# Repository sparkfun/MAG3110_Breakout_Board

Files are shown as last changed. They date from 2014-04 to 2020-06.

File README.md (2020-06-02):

**NOTE:** *This product has been retired from our catalog. If you are looking for more up-to-date info, please check out some of these resources to see how other users are still hacking and improving on this product.*
* *[SparkFun Forum](https://forum.sparkfun.com/)*
* *[Comments Here on GitHub](https://github.com/sparkfun/MAG3110_Breakout_Board/issues)*

Triple Axis Magnetometer Breakout - MAG3110
============================================

_MAG-3110 (https://www.sparkfun.com/products/12670)_

[*Triple Axis Magnetometer Breakout - MAG3110 (SEN-12670)*](https://www.sparkfun.com/products/12670)

Breakout board for MAG3110 digital magnetometer [The datasheet can be found here.](https://dlnmh9ip6v2uc.cloudfront.net/datasheets/Sensors/Magneto/MAG3110.pdf)

This board was created in Eagle v6.5.0. 

Repository Contents
-------------------

* **/Hardware** - All Eagle design files (.brd and .sch)
* **/Libraries** - Arduino libraries
* **/Production** - Production panel files

Documentation
--------------

* **[Library](https://github.com/sparkfun/SparkFun_MAG3110_Breakout_Board_Arduino_Library)** - Arduino library 
* **[Hookup Guide](https://learn.sparkfun.com/tutorials/mag3110-magnetometer-hookup-guide-)** - Basic hookup guide 
* **[SparkFun Fritzing repo](https://github.com/sparkfun/Fritzing_Parts)** - Fritzing diagrams for SparkFun products.
* **[SparkFun 3D Model repo](https://github.com/sparkfun/3D_Models)** - 3D models of SparkFun products. 
* **[SparkFun Graphical Datasheets](https://github.com/sparkfun/Graphical_Datasheets)** -Graphical Datasheets for various SparkFun products.

Version History
---------------

* [V_H1.2](https://github.com/sparkfun/MAG3110_Breakout_Board/releases/tag/vH1.2) - Removing old libraries. Adding links to formal libs in readme.
* [V_H1.2_L1.1.0](https://github.com/sparkfun/MAG3110_Breakout_Board/releases/tag/vH1.2_L1.0)

Product Versions
---------------

* [SEN-10619](https://www.sparkfun.com/products/12670) - Version 1.2
* [SEN-10619](https://www.sparkfun.com/products/retired/10619) - Version 1.1 of the Sensor
 
License Information
-------------------
This product is _**open source**_! 

Please review the LICENSE.md file for license information. 

If you have any questions or concerns on licensing, please contact technical support on our [SparkFun forums](https://forum.sparkfun.com/viewforum.php?f=152).

Distributed as-is; no warranty is given.

- Your friends at SparkFun.

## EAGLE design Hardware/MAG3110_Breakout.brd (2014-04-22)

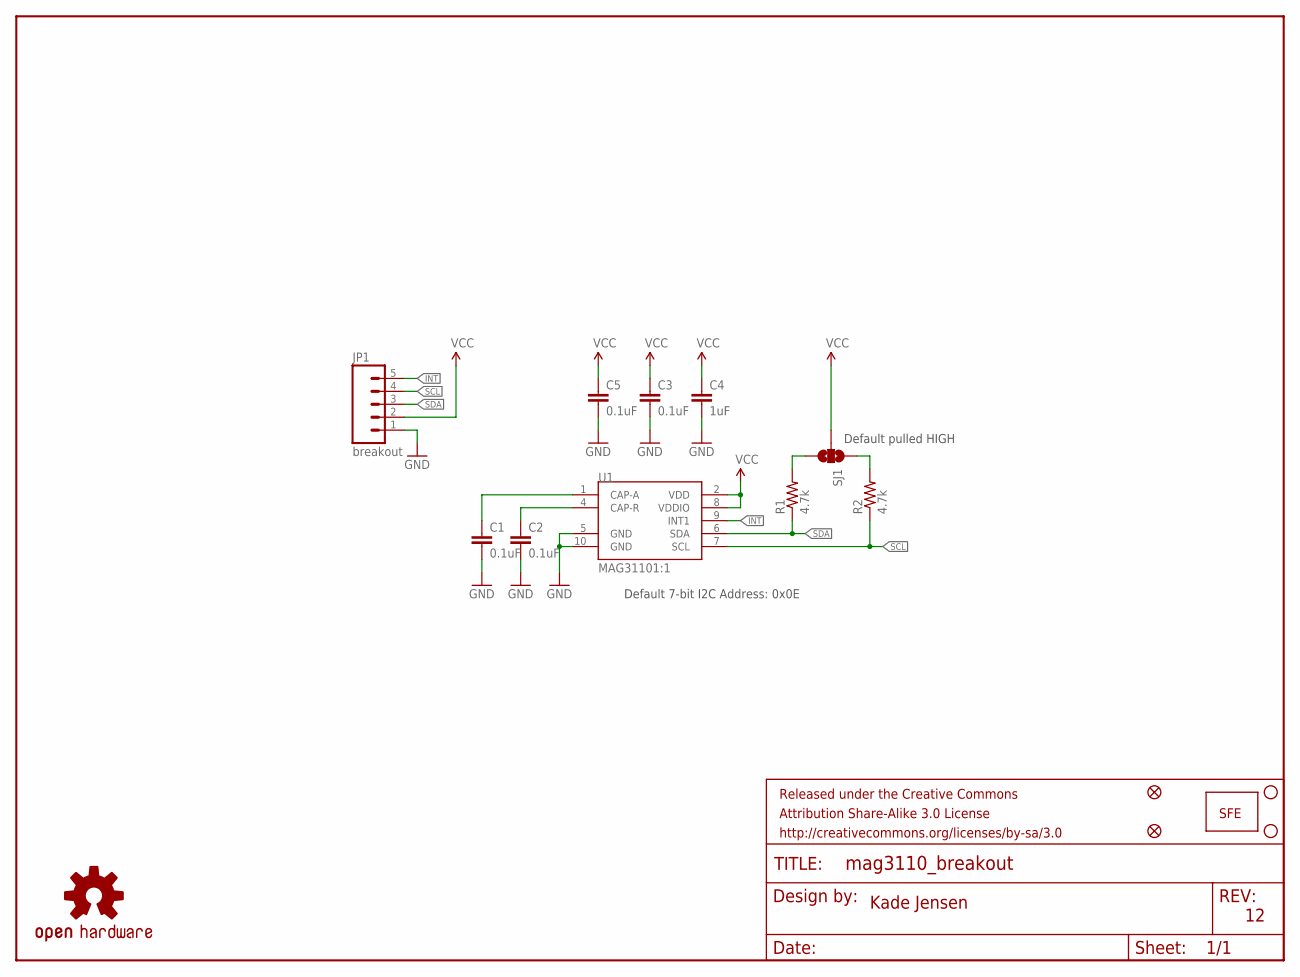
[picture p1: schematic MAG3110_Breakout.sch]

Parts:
C1, C2, C3, C5: 0.1uF; 0603-CAP
C4: 1uF; 0603-CAP
FID1, FID2: FIDUCIAL1X2; FIDUCIAL-1X2
FRAME2: FRAME-LETTER; CREATIVE_COMMONS
JP1: breakout; 1X05
JP2, JP3: STAND-OFF
JP7: LOGO-SFESK; SFE-LOGO-FLAME
LOGO1: OSHW-LOGOS; OSHW-LOGO-S
R1, R2: 4.7k; 0603-RES
SJ1: SOLDERJUMPER_2WAYPASTE1&2&3; SJ_3_PASTE1&2&3
U1: MAG31101:1; DFN-10-W

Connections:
GND: C1.2, C2.2, C3.2, C4.2, C5.2, JP1.1, U1.5 (GND), U1.10 (GND)
INT: JP1.5, U1.9 (INT1)
unnamed: C2.1, U1.4 (CAP-R)
unnamed: C1.1, U1.1 (CAP-A)
unnamed: R2.2, SJ1.1
unnamed: R1.2, SJ1.3
SCL: JP1.4, R2.1, U1.7 (SCL)
SDA: JP1.3, R1.1, U1.6 (SDA)
VCC: C3.1, C4.1, C5.1, JP1.2, SJ1.2, U1.2 (VDD), U1.8 (VDDIO)

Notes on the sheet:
Kade Jensen
Default pulled HIGH
Default 7-bit I2C Address: 0x0E

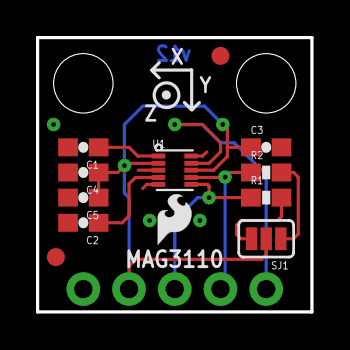
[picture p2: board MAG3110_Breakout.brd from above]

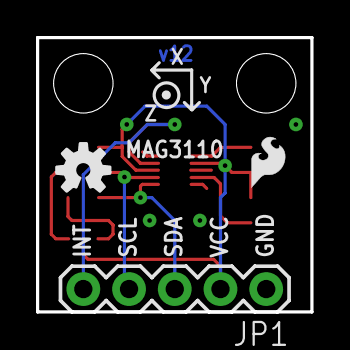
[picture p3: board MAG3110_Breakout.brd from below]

Board: 2 copper layers, 15.2 x 15.2 mm, 18 parts (3 on the bottom side), 9 nets.

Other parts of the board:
JP4: LOGO-SFESK; SFE-LOGO-FLAME

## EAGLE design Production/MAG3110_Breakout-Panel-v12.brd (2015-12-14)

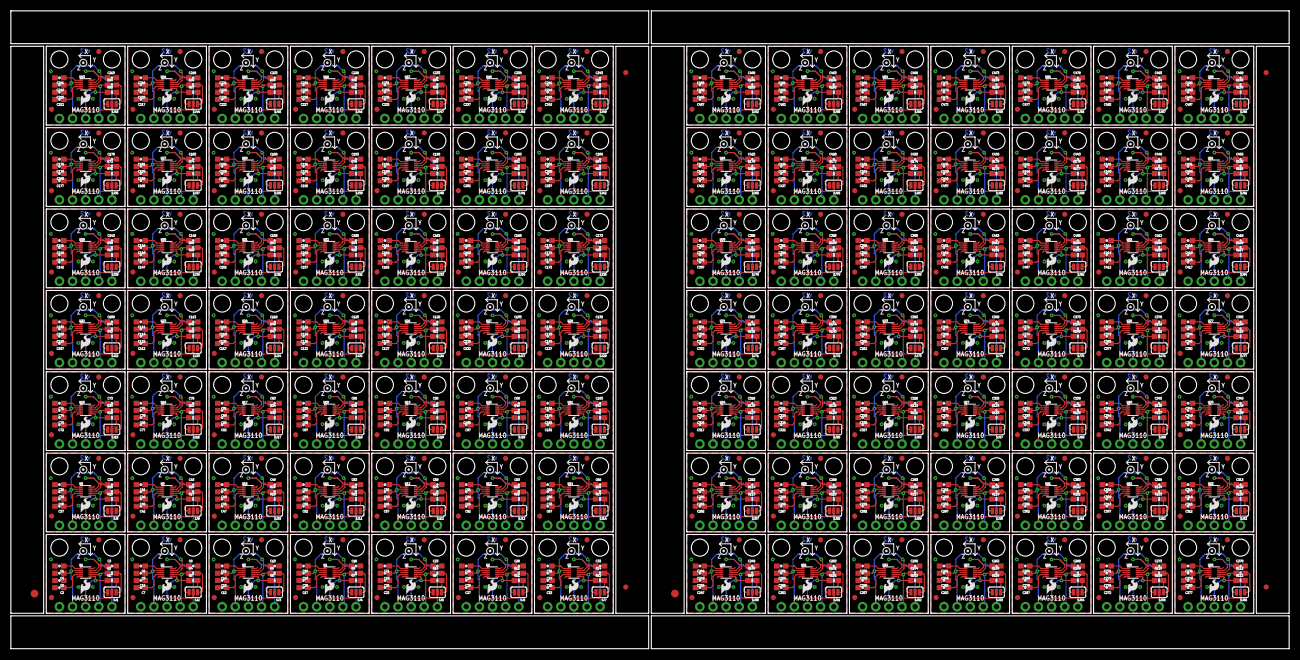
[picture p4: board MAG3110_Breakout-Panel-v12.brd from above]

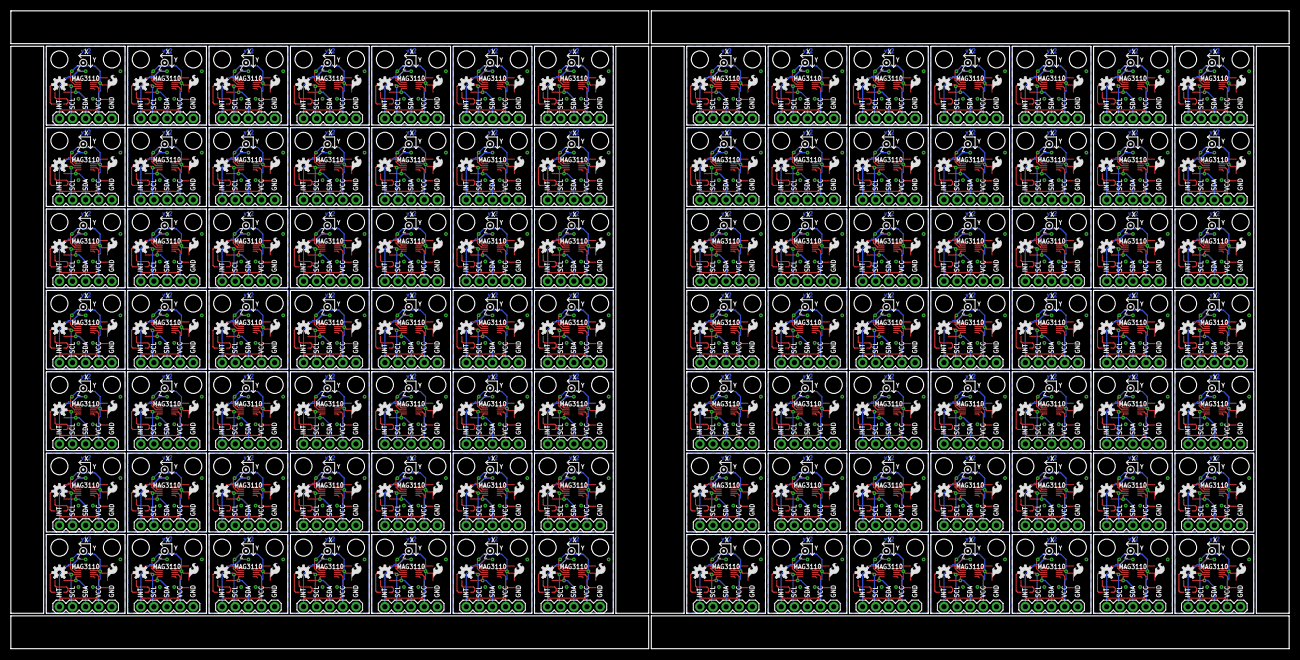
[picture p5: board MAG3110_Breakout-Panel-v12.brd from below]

Board: 2 copper layers, 247.4 x 123.4 mm, 1672 parts (294 on the bottom side), 882 nets.

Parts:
C1, C2, C3, C5, C6, C7, C8, C10, C11, C12, C13, C15, C16, C17, C18, C20, C21, C22, C23, C25, C26, C27, C28, C30, C31, C32, C33, C35, C36, C37, C38, C40, C41, C42, C43, C45, C46, C47, C48, C50, C51, C52, C53, C55, C56, C57, C58, C60, C61, C62, C63, C65, C66, C67, C68, C70, C71, C72, C73, C75, C76, C77, C78, C80, C81, C82, C83, C85, C86, C87, C88, C90, C91, C92, C93, C95, C96, C97, C98, C100, C101, C102, C103, C105, C106, C107, C108, C110, C111, C112, C113, C115, C116, C117, C118, C120, C121, C122, C123, C125, C126, C127, C128, C130, C131, C132, C133, C135, C136, C137, C138, C140, C141, C142, C143, C145, C146, C147, C148, C150, C151, C152, C153, C155, C156, C157, C158, C160, C161, C162, C163, C165, C166, C167, C168, C170, C171, C172, C173, C175, C176, C177, C178, C180, C181, C182, C183, C185, C186, C187, C188, C190, C191, C192, C193, C195, C196, C197, C198, C200, C201, C202, C203, C205, C206, C207, C208, C210, C211, C212, C213, C215, C216, C217, C218, C220, C221, C222, C223, C225, C226, C227, C228, C230, C231, C232, C233, C235, C236, C237, C238, C240, C241, C242, C243, C245, C246, C247, C248, C250, C251, C252, C253, C255, C256, C257, C258, C260, C261, C262, C263, C265, C266, C267, C268, C270, C271, C272, C273, C275, C276, C277, C278, C280, C281, C282, C283, C285, C286, C287, C288, C290, C291, C292, C293, C295, C296, C297, C298, C300, C301, C302, C303, C305, C306, C307, C308, C310, C311, C312, C313, C315, C316, C317, C318, C320, C321, C322, C323, C325, C326, C327, C328, C330, C331, C332, C333, C335, C336, C337, C338, C340, C341, C342, C343, C345, C346, C347, C348, C350, C351, C352, C353, C355, C356, C357, C358, C360, C361, C362, C363, C365, C366, C367, C368, C370, C371, C372, C373, C375, C376, C377, C378, C380, C381, C382, C383, C385, C386, C387, C388, C390, C391, C392, C393, C395, C396, C397, C398, C400, C401, C402, C403, C405, C406, C407, C408, C410, C411, C412, C413, C415, C416, C417, C418, C420, C421, C422, C423, C425, C426, C427, C428, C430, C431, C432, C433, C435, C436, C437, C438, C440, C441, C442, C443, C445, C446, C447, C448, C450, C451, C452, C453, C455, C456, C457, C458, C460, C461, C462, C463, C465, C466, C467, C468, C470, C471, C472, C473, C475, C476, C477, C478, C480, C481, C482, C483, C485, C486, C487, C488, C490: 0.1uF; 0603-CAP
C4, C9, C14, C19, C24, C29, C34, C39, C44, C49, C54, C59, C64, C69, C74, C79, C84, C89, C94, C99, C104, C109, C114, C119, C124, C129, C134, C139, C144, C149, C154, C159, C164, C169, C174, C179, C184, C189, C194, C199, C204, C209, C214, C219, C224, C229, C234, C239, C244, C249, C254, C259, C264, C269, C274, C279, C284, C289, C294, C299, C304, C309, C314, C319, C324, C329, C334, C339, C344, C349, C354, C359, C364, C369, C374, C379, C384, C389, C394, C399, C404, C409, C414, C419, C424, C429, C434, C439, C444, C449, C454, C459, C464, C469, C474, C479, C484, C489: 1uF; 0603-CAP
E$1, E$5: FIDUCIAL-1.5X3
E$2, E$3, E$4, E$6: FIDUCIAL-1X2
FID1, FID2, FID3, FID4, FID5, FID6, FID7, FID8, FID9, FID10, FID11, FID12, FID13, FID14, FID15, FID16, FID17, FID18, FID19, FID20, FID21, FID22, FID23, FID24, FID25, FID26, FID27, FID28, FID29, FID30, FID31, FID32, FID33, FID34, FID35, FID36, FID37, FID38, FID39, FID40, FID41, FID42, FID43, FID44, FID45, FID46, FID47, FID48, FID49, FID50, FID51, FID52, FID53, FID54, FID55, FID56, FID57, FID58, FID59, FID60, FID61, FID62, FID63, FID64, FID65, FID66, FID67, FID68, FID69, FID70, FID71, FID72, FID73, FID74, FID75, FID76, FID77, FID78, FID79, FID80, FID81, FID82, FID83, FID84, FID85, FID86, FID87, FID88, FID89, FID90, FID91, FID92, FID93, FID94, FID95, FID96, FID97, FID98, FID99, FID100, FID101, FID102, FID103, FID104, FID105, FID106, FID107, FID108, FID109, FID110, FID111, FID112, FID113, FID114, FID115, FID116, FID117, FID118, FID119, FID120, FID121, FID122, FID123, FID124, FID125, FID126, FID127, FID128, FID129, FID130, FID131, FID132, FID133, FID134, FID135, FID136, FID137, FID138, FID139, FID140, FID141, FID142, FID143, FID144, FID145, FID146, FID147, FID148, FID149, FID150, FID151, FID152, FID153, FID154, FID155, FID156, FID157, FID158, FID159, FID160, FID161, FID162, FID163, FID164, FID165, FID166, FID167, FID168, FID169, FID170, FID171, FID172, FID173, FID174, FID175, FID176, FID177, FID178, FID179, FID180, FID181, FID182, FID183, FID184, FID185, FID186, FID187, FID188, FID189, FID190, FID191, FID192, FID193, FID194, FID195, FID196: FIDUCIAL1X2; FIDUCIAL-1X2
JP1, JP5, JP11, JP16, JP21, JP26, JP31, JP36, JP41, JP46, JP51, JP56, JP61, JP66, JP71, JP76, JP81, JP86, JP91, JP96, JP101, JP106, JP111, JP116, JP121, JP126, JP131, JP136, JP141, JP146, JP151, JP156, JP161, JP166, JP171, JP176, JP181, JP186, JP191, JP196, JP201, JP206, JP211, JP216, JP221, JP226, JP231, JP236, JP241, JP246, JP251, JP256, JP261, JP266, JP271, JP276, JP281, JP286, JP291, JP296, JP301, JP306, JP311, JP316, JP321, JP326, JP331, JP336, JP341, JP346, JP351, JP356, JP361, JP366, JP371, JP376, JP381, JP386, JP391, JP396, JP401, JP406, JP411, JP416, JP421, JP426, JP431, JP436, JP441, JP446, JP451, JP456, JP461, JP466, JP471, JP476, JP481, JP486: breakout; 1X05
JP2, JP3, JP6, JP8, JP12, JP13, JP17, JP18, JP22, JP23, JP27, JP28, JP32, JP33, JP37, JP38, JP42, JP43, JP47, JP48, JP52, JP53, JP57, JP58, JP62, JP63, JP67, JP68, JP72, JP73, JP77, JP78, JP82, JP83, JP87, JP88, JP92, JP93, JP97, JP98, JP102, JP103, JP107, JP108, JP112, JP113, JP117, JP118, JP122, JP123, JP127, JP128, JP132, JP133, JP137, JP138, JP142, JP143, JP147, JP148, JP152, JP153, JP157, JP158, JP162, JP163, JP167, JP168, JP172, JP173, JP177, JP178, JP182, JP183, JP187, JP188, JP192, JP193, JP197, JP198, JP202, JP203, JP207, JP208, JP212, JP213, JP217, JP218, JP222, JP223, JP227, JP228, JP232, JP233, JP237, JP238, JP242, JP243, JP247, JP248, JP252, JP253, JP257, JP258, JP262, JP263, JP267, JP268, JP272, JP273, JP277, JP278, JP282, JP283, JP287, JP288, JP292, JP293, JP297, JP298, JP302, JP303, JP307, JP308, JP312, JP313, JP317, JP318, JP322, JP323, JP327, JP328, JP332, JP333, JP337, JP338, JP342, JP343, JP347, JP348, JP352, JP353, JP357, JP358, JP362, JP363, JP367, JP368, JP372, JP373, JP377, JP378, JP382, JP383, JP387, JP388, JP392, JP393, JP397, JP398, JP402, JP403, JP407, JP408, JP412, JP413, JP417, JP418, JP422, JP423, JP427, JP428, JP432, JP433, JP437, JP438, JP442, JP443, JP447, JP448, JP452, JP453, JP457, JP458, JP462, JP463, JP467, JP468, JP472, JP473, JP477, JP478, JP482, JP483, JP487, JP488: STAND-OFF
JP4, JP7, JP9, JP10, JP14, JP15, JP19, JP20, JP24, JP25, JP29, JP30, JP34, JP35, JP39, JP40, JP44, JP45, JP49, JP50, JP54, JP55, JP59, JP60, JP64, JP65, JP69, JP70, JP74, JP75, JP79, JP80, JP84, JP85, JP89, JP90, JP94, JP95, JP99, JP100, JP104, JP105, JP109, JP110, JP114, JP115, JP119, JP120, JP124, JP125, JP129, JP130, JP134, JP135, JP139, JP140, JP144, JP145, JP149, JP150, JP154, JP155, JP159, JP160, JP164, JP165, JP169, JP170, JP174, JP175, JP179, JP180, JP184, JP185, JP189, JP190, JP194, JP195, JP199, JP200, JP204, JP205, JP209, JP210, JP214, JP215, JP219, JP220, JP224, JP225, JP229, JP230, JP234, JP235, JP239, JP240, JP244, JP245, JP249, JP250, JP254, JP255, JP259, JP260, JP264, JP265, JP269, JP270, JP274, JP275, JP279, JP280, JP284, JP285, JP289, JP290, JP294, JP295, JP299, JP300, JP304, JP305, JP309, JP310, JP314, JP315, JP319, JP320, JP324, JP325, JP329, JP330, JP334, JP335, JP339, JP340, JP344, JP345, JP349, JP350, JP354, JP355, JP359, JP360, JP364, JP365, JP369, JP370, JP374, JP375, JP379, JP380, JP384, JP385, JP389, JP390, JP394, JP395, JP399, JP400, JP404, JP405, JP409, JP410, JP414, JP415, JP419, JP420, JP424, JP425, JP429, JP430, JP434, JP435, JP439, JP440, JP444, JP445, JP449, JP450, JP454, JP455, JP459, JP460, JP464, JP465, JP469, JP470, JP474, JP475, JP479, JP480, JP484, JP485, JP489, JP490: LOGO-SFESK; SFE-LOGO-FLAME
LOGO1, LOGO2, LOGO3, LOGO4, LOGO5, LOGO6, LOGO7, LOGO8, LOGO9, LOGO10, LOGO11, LOGO12, LOGO13, LOGO14, LOGO15, LOGO16, LOGO17, LOGO18, LOGO19, LOGO20, LOGO21, LOGO22, LOGO23, LOGO24, LOGO25, LOGO26, LOGO27, LOGO28, LOGO29, LOGO30, LOGO31, LOGO32, LOGO33, LOGO34, LOGO35, LOGO36, LOGO37, LOGO38, LOGO39, LOGO40, LOGO41, LOGO42, LOGO43, LOGO44, LOGO45, LOGO46, LOGO47, LOGO48, LOGO49, LOGO50, LOGO51, LOGO52, LOGO53, LOGO54, LOGO55, LOGO56, LOGO57, LOGO58, LOGO59, LOGO60, LOGO61, LOGO62, LOGO63, LOGO64, LOGO65, LOGO66, LOGO67, LOGO68, LOGO69, LOGO70, LOGO71, LOGO72, LOGO73, LOGO74, LOGO75, LOGO76, LOGO77, LOGO78, LOGO79, LOGO80, LOGO81, LOGO82, LOGO83, LOGO84, LOGO85, LOGO86, LOGO87, LOGO88, LOGO89, LOGO90, LOGO91, LOGO92, LOGO93, LOGO94, LOGO95, LOGO96, LOGO97, LOGO98: OSHW-LOGOS; OSHW-LOGO-S
R1, R2, R3, R4, R5, R6, R7, R8, R9, R10, R11, R12, R13, R14, R15, R16, R17, R18, R19, R20, R21, R22, R23, R24, R25, R26, R27, R28, R29, R30, R31, R32, R33, R34, R35, R36, R37, R38, R39, R40, R41, R42, R43, R44, R45, R46, R47, R48, R49, R50, R51, R52, R53, R54, R55, R56, R57, R58, R59, R60, R61, R62, R63, R64, R65, R66, R67, R68, R69, R70, R71, R72, R73, R74, R75, R76, R77, R78, R79, R80, R81, R82, R83, R84, R85, R86, R87, R88, R89, R90, R91, R92, R93, R94, R95, R96, R97, R98, R99, R100, R101, R102, R103, R104, R105, R106, R107, R108, R109, R110, R111, R112, R113, R114, R115, R116, R117, R118, R119, R120, R121, R122, R123, R124, R125, R126, R127, R128, R129, R130, R131, R132, R133, R134, R135, R136, R137, R138, R139, R140, R141, R142, R143, R144, R145, R146, R147, R148, R149, R150, R151, R152, R153, R154, R155, R156, R157, R158, R159, R160, R161, R162, R163, R164, R165, R166, R167, R168, R169, R170, R171, R172, R173, R174, R175, R176, R177, R178, R179, R180, R181, R182, R183, R184, R185, R186, R187, R188, R189, R190, R191, R192, R193, R194, R195, R196: 4.7k; 0603-RES
SJ1, SJ2, SJ3, SJ4, SJ5, SJ6, SJ7, SJ8, SJ9, SJ10, SJ11, SJ12, SJ13, SJ14, SJ15, SJ16, SJ17, SJ18, SJ19, SJ20, SJ21, SJ22, SJ23, SJ24, SJ25, SJ26, SJ27, SJ28, SJ29, SJ30, SJ31, SJ32, SJ33, SJ34, SJ35, SJ36, SJ37, SJ38, SJ39, SJ40, SJ41, SJ42, SJ43, SJ44, SJ45, SJ46, SJ47, SJ48, SJ49, SJ50, SJ51, SJ52, SJ53, SJ54, SJ55, SJ56, SJ57, SJ58, SJ59, SJ60, SJ61, SJ62, SJ63, SJ64, SJ65, SJ66, SJ67, SJ68, SJ69, SJ70, SJ71, SJ72, SJ73, SJ74, SJ75, SJ76, SJ77, SJ78, SJ79, SJ80, SJ81, SJ82, SJ83, SJ84, SJ85, SJ86, SJ87, SJ88, SJ89, SJ90, SJ91, SJ92, SJ93, SJ94, SJ95, SJ96, SJ97, SJ98: SJ_3_PASTE1&2&3
U1, U2, U3, U4, U5, U6, U7, U8, U9, U10, U11, U12, U13, U14, U15, U16, U17, U18, U19, U20, U21, U22, U23, U24, U25, U26, U27, U28, U29, U30, U31, U32, U33, U34, U35, U36, U37, U38, U39, U40, U41, U42, U43, U44, U45, U46, U47, U48, U49, U50, U51, U52, U53, U54, U55, U56, U57, U58, U59, U60, U61, U62, U63, U64, U65, U66, U67, U68, U69, U70, U71, U72, U73, U74, U75, U76, U77, U78, U79, U80, U81, U82, U83, U84, U85, U86, U87, U88, U89, U90, U91, U92, U93, U94, U95, U96, U97, U98: MAG31101:1; DFN-10-W

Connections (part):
GND: C1.2, C2.2, C3.2, C4.2, C5.2, JP1.1, U1.5, U1.10
GND1: C6.2, C7.2, C8.2, C9.2, C10.2, JP5.1, U2.5, U2.10
GND2: C11.2, C12.2, C13.2, C14.2, C15.2, JP11.1, U3.5, U3.10
GND3: C16.2, C17.2, C18.2, C19.2, C20.2, JP16.1, U4.5, U4.10
GND4: C21.2, C22.2, C23.2, C24.2, C25.2, JP21.1, U5.5, U5.10
GND5: C26.2, C27.2, C28.2, C29.2, C30.2, JP26.1, U6.5, U6.10
GND6: C31.2, C32.2, C33.2, C34.2, C35.2, JP31.1, U7.5, U7.10
GND7: C36.2, C37.2, C38.2, C39.2, C40.2, JP36.1, U8.5, U8.10
GND8: C41.2, C42.2, C43.2, C44.2, C45.2, JP41.1, U9.5, U9.10
GND9: C46.2, C47.2, C48.2, C49.2, C50.2, JP46.1, U10.5, U10.10
GND10: C51.2, C52.2, C53.2, C54.2, C55.2, JP51.1, U11.5, U11.10
GND11: C56.2, C57.2, C58.2, C59.2, C60.2, JP56.1, U12.5, U12.10
GND12: C61.2, C62.2, C63.2, C64.2, C65.2, JP61.1, U13.5, U13.10
GND13: C66.2, C67.2, C68.2, C69.2, C70.2, JP66.1, U14.5, U14.10
GND14: C71.2, C72.2, C73.2, C74.2, C75.2, JP71.1, U15.5, U15.10
GND15: C76.2, C77.2, C78.2, C79.2, C80.2, JP76.1, U16.5, U16.10
GND16: C81.2, C82.2, C83.2, C84.2, C85.2, JP81.1, U17.5, U17.10
GND17: C86.2, C87.2, C88.2, C89.2, C90.2, JP86.1, U18.5, U18.10
GND18: C91.2, C92.2, C93.2, C94.2, C95.2, JP91.1, U19.5, U19.10
GND19: C96.2, C97.2, C98.2, C99.2, C100.2, JP96.1, U20.5, U20.10
GND20: C101.2, C102.2, C103.2, C104.2, C105.2, JP101.1, U21.5, U21.10
GND21: C106.2, C107.2, C108.2, C109.2, C110.2, JP106.1, U22.5, U22.10
GND22: C111.2, C112.2, C113.2, C114.2, C115.2, JP111.1, U23.5, U23.10
GND23: C116.2, C117.2, C118.2, C119.2, C120.2, JP116.1, U24.5, U24.10
GND24: C121.2, C122.2, C123.2, C124.2, C125.2, JP121.1, U25.5, U25.10
GND25: C126.2, C127.2, C128.2, C129.2, C130.2, JP126.1, U26.5, U26.10
GND26: C131.2, C132.2, C133.2, C134.2, C135.2, JP131.1, U27.5, U27.10
GND27: C136.2, C137.2, C138.2, C139.2, C140.2, JP136.1, U28.5, U28.10
GND28: C141.2, C142.2, C143.2, C144.2, C145.2, JP141.1, U29.5, U29.10
GND29: C146.2, C147.2, C148.2, C149.2, C150.2, JP146.1, U30.5, U30.10
GND30: C151.2, C152.2, C153.2, C154.2, C155.2, JP151.1, U31.5, U31.10
GND31: C156.2, C157.2, C158.2, C159.2, C160.2, JP156.1, U32.5, U32.10
GND32: C161.2, C162.2, C163.2, C164.2, C165.2, JP161.1, U33.5, U33.10
GND33: C166.2, C167.2, C168.2, C169.2, C170.2, JP166.1, U34.5, U34.10
GND34: C171.2, C172.2, C173.2, C174.2, C175.2, JP171.1, U35.5, U35.10
GND35: C176.2, C177.2, C178.2, C179.2, C180.2, JP176.1, U36.5, U36.10
GND36: C181.2, C182.2, C183.2, C184.2, C185.2, JP181.1, U37.5, U37.10
GND37: C186.2, C187.2, C188.2, C189.2, C190.2, JP186.1, U38.5, U38.10
GND38: C191.2, C192.2, C193.2, C194.2, C195.2, JP191.1, U39.5, U39.10
GND39: C196.2, C197.2, C198.2, C199.2, C200.2, JP196.1, U40.5, U40.10
GND40: C201.2, C202.2, C203.2, C204.2, C205.2, JP201.1, U41.5, U41.10
GND41: C206.2, C207.2, C208.2, C209.2, C210.2, JP206.1, U42.5, U42.10
GND42: C211.2, C212.2, C213.2, C214.2, C215.2, JP211.1, U43.5, U43.10
GND43: C216.2, C217.2, C218.2, C219.2, C220.2, JP216.1, U44.5, U44.10
GND44: C221.2, C222.2, C223.2, C224.2, C225.2, JP221.1, U45.5, U45.10
GND45: C226.2, C227.2, C228.2, C229.2, C230.2, JP226.1, U46.5, U46.10
GND46: C231.2, C232.2, C233.2, C234.2, C235.2, JP231.1, U47.5, U47.10
GND47: C236.2, C237.2, C238.2, C239.2, C240.2, JP236.1, U48.5, U48.10
GND48: C241.2, C242.2, C243.2, C244.2, C245.2, JP241.1, U49.5, U49.10
GND49: C246.2, C247.2, C248.2, C249.2, C250.2, JP246.1, U50.5, U50.10
GND50: C251.2, C252.2, C253.2, C254.2, C255.2, JP251.1, U51.5, U51.10
GND51: C256.2, C257.2, C258.2, C259.2, C260.2, JP256.1, U52.5, U52.10
GND52: C261.2, C262.2, C263.2, C264.2, C265.2, JP261.1, U53.5, U53.10
GND53: C266.2, C267.2, C268.2, C269.2, C270.2, JP266.1, U54.5, U54.10
GND54: C271.2, C272.2, C273.2, C274.2, C275.2, JP271.1, U55.5, U55.10
GND55: C276.2, C277.2, C278.2, C279.2, C280.2, JP276.1, U56.5, U56.10
GND56: C281.2, C282.2, C283.2, C284.2, C285.2, JP281.1, U57.5, U57.10
GND57: C286.2, C287.2, C288.2, C289.2, C290.2, JP286.1, U58.5, U58.10
GND58: C291.2, C292.2, C293.2, C294.2, C295.2, JP291.1, U59.5, U59.10
GND59: C296.2, C297.2, C298.2, C299.2, C300.2, JP296.1, U60.5, U60.10
GND60: C301.2, C302.2, C303.2, C304.2, C305.2, JP301.1, U61.5, U61.10
GND61: C306.2, C307.2, C308.2, C309.2, C310.2, JP306.1, U62.5, U62.10
GND62: C311.2, C312.2, C313.2, C314.2, C315.2, JP311.1, U63.5, U63.10
GND63: C316.2, C317.2, C318.2, C319.2, C320.2, JP316.1, U64.5, U64.10
GND64: C321.2, C322.2, C323.2, C324.2, C325.2, JP321.1, U65.5, U65.10
GND65: C326.2, C327.2, C328.2, C329.2, C330.2, JP326.1, U66.5, U66.10
GND66: C331.2, C332.2, C333.2, C334.2, C335.2, JP331.1, U67.5, U67.10
GND67: C336.2, C337.2, C338.2, C339.2, C340.2, JP336.1, U68.5, U68.10
GND68: C341.2, C342.2, C343.2, C344.2, C345.2, JP341.1, U69.5, U69.10
GND69: C346.2, C347.2, C348.2, C349.2, C350.2, JP346.1, U70.5, U70.10
GND70: C351.2, C352.2, C353.2, C354.2, C355.2, JP351.1, U71.5, U71.10
GND71: C356.2, C357.2, C358.2, C359.2, C360.2, JP356.1, U72.5, U72.10
GND72: C361.2, C362.2, C363.2, C364.2, C365.2, JP361.1, U73.5, U73.10
GND73: C366.2, C367.2, C368.2, C369.2, C370.2, JP366.1, U74.5, U74.10
GND74: C371.2, C372.2, C373.2, C374.2, C375.2, JP371.1, U75.5, U75.10
GND75: C376.2, C377.2, C378.2, C379.2, C380.2, JP376.1, U76.5, U76.10
GND76: C381.2, C382.2, C383.2, C384.2, C385.2, JP381.1, U77.5, U77.10
GND77: C386.2, C387.2, C388.2, C389.2, C390.2, JP386.1, U78.5, U78.10
GND78: C391.2, C392.2, C393.2, C394.2, C395.2, JP391.1, U79.5, U79.10
GND79: C396.2, C397.2, C398.2, C399.2, C400.2, JP396.1, U80.5, U80.10
GND80: C401.2, C402.2, C403.2, C404.2, C405.2, JP401.1, U81.5, U81.10
GND81: C406.2, C407.2, C408.2, C409.2, C410.2, JP406.1, U82.5, U82.10
GND82: C411.2, C412.2, C413.2, C414.2, C415.2, JP411.1, U83.5, U83.10
GND83: C416.2, C417.2, C418.2, C419.2, C420.2, JP416.1, U84.5, U84.10
GND84: C421.2, C422.2, C423.2, C424.2, C425.2, JP421.1, U85.5, U85.10
GND85: C426.2, C427.2, C428.2, C429.2, C430.2, JP426.1, U86.5, U86.10
GND86: C431.2, C432.2, C433.2, C434.2, C435.2, JP431.1, U87.5, U87.10
GND87: C436.2, C437.2, C438.2, C439.2, C440.2, JP436.1, U88.5, U88.10
GND88: C441.2, C442.2, C443.2, C444.2, C445.2, JP441.1, U89.5, U89.10
GND89: C446.2, C447.2, C448.2, C449.2, C450.2, JP446.1, U90.5, U90.10
GND90: C451.2, C452.2, C453.2, C454.2, C455.2, JP451.1, U91.5, U91.10
GND91: C456.2, C457.2, C458.2, C459.2, C460.2, JP456.1, U92.5, U92.10
GND92: C461.2, C462.2, C463.2, C464.2, C465.2, JP461.1, U93.5, U93.10
GND93: C466.2, C467.2, C468.2, C469.2, C470.2, JP466.1, U94.5, U94.10
GND94: C471.2, C472.2, C473.2, C474.2, C475.2, JP471.1, U95.5, U95.10
GND95: C476.2, C477.2, C478.2, C479.2, C480.2, JP476.1, U96.5, U96.10
GND96: C481.2, C482.2, C483.2, C484.2, C485.2, JP481.1, U97.5, U97.10
GND97: C486.2, C487.2, C488.2, C489.2, C490.2, JP486.1, U98.5, U98.10
INT: JP1.5, U1.9
INT1: JP5.5, U2.9
INT2: JP11.5, U3.9
INT3: JP16.5, U4.9
INT4: JP21.5, U5.9
INT5: JP26.5, U6.9
INT6: JP31.5, U7.9
INT7: JP36.5, U8.9
INT8: JP41.5, U9.9
INT9: JP46.5, U10.9
INT10: JP51.5, U11.9
INT11: JP56.5, U12.9
INT12: JP61.5, U13.9
INT13: JP66.5, U14.9
INT14: JP71.5, U15.9
INT15: JP76.5, U16.9
INT16: JP81.5, U17.9
INT17: JP86.5, U18.9
INT18: JP91.5, U19.9
INT19: JP96.5, U20.9
INT20: JP101.5, U21.9
INT21: JP106.5, U22.9
INT22: JP111.5, U23.9
INT23: JP116.5, U24.9
INT24: JP121.5, U25.9
INT25: JP126.5, U26.9
INT26: JP131.5, U27.9
INT27: JP136.5, U28.9
INT28: JP141.5, U29.9
INT29: JP146.5, U30.9
INT30: JP151.5, U31.9
INT31: JP156.5, U32.9
INT32: JP161.5, U33.9
INT33: JP166.5, U34.9
INT34: JP171.5, U35.9
INT35: JP176.5, U36.9
INT36: JP181.5, U37.9
INT37: JP186.5, U38.9
INT38: JP191.5, U39.9
INT39: JP196.5, U40.9
INT40: JP201.5, U41.9
INT41: JP206.5, U42.9
INT42: JP211.5, U43.9
INT43: JP216.5, U44.9
INT44: JP221.5, U45.9
INT45: JP226.5, U46.9
INT46: JP231.5, U47.9
INT47: JP236.5, U48.9
INT48: JP241.5, U49.9
INT49: JP246.5, U50.9
INT50: JP251.5, U51.9
INT51: JP256.5, U52.9
INT52: JP261.5, U53.9
INT53: JP266.5, U54.9
INT54: JP271.5, U55.9
INT55: JP276.5, U56.9
INT56: JP281.5, U57.9
INT57: JP286.5, U58.9
INT58: JP291.5, U59.9
INT59: JP296.5, U60.9
INT60: JP301.5, U61.9
INT61: JP306.5, U62.9
INT62: JP311.5, U63.9
INT63: JP316.5, U64.9
INT64: JP321.5, U65.9
INT65: JP326.5, U66.9
INT66: JP331.5, U67.9
INT67: JP336.5, U68.9
INT68: JP341.5, U69.9
INT69: JP346.5, U70.9
INT70: JP351.5, U71.9
INT71: JP356.5, U72.9
INT72: JP361.5, U73.9
INT73: JP366.5, U74.9
INT74: JP371.5, U75.9
INT75: JP376.5, U76.9
INT76: JP381.5, U77.9
INT77: JP386.5, U78.9
INT78: JP391.5, U79.9
INT79: JP396.5, U80.9
INT80: JP401.5, U81.9
INT81: JP406.5, U82.9
INT82: JP411.5, U83.9
INT83: JP416.5, U84.9
INT84: JP421.5, U85.9
INT85: JP426.5, U86.9
INT86: JP431.5, U87.9
INT87: JP436.5, U88.9
INT88: JP441.5, U89.9
INT89: JP446.5, U90.9
INT90: JP451.5, U91.9
INT91: JP456.5, U92.9
INT92: JP461.5, U93.9
INT93: JP466.5, U94.9
INT94: JP471.5, U95.9
INT95: JP476.5, U96.9
INT96: JP481.5, U97.9
INT97: JP486.5, U98.9
unnamed: C2.1, U1.4
unnamed: C1.1, U1.1
unnamed: R2.2, SJ1.1
unnamed: R1.2, SJ1.3
unnamed: C7.1, U2.4
unnamed: C6.1, U2.1
unnamed: R4.2, SJ2.1
unnamed: R3.2, SJ2.3
unnamed: C12.1, U3.4
unnamed: C11.1, U3.1
unnamed: R6.2, SJ3.1
unnamed: R5.2, SJ3.3
unnamed: C17.1, U4.4
unnamed: C16.1, U4.1
unnamed: R8.2, SJ4.1
unnamed: R7.2, SJ4.3
unnamed: C22.1, U5.4
unnamed: C21.1, U5.1
unnamed: R10.2, SJ5.1
unnamed: R9.2, SJ5.3
unnamed: C27.1, U6.4
unnamed: C26.1, U6.1
unnamed: R12.2, SJ6.1
unnamed: R11.2, SJ6.3
unnamed: C32.1, U7.4
unnamed: C31.1, U7.1
unnamed: R14.2, SJ7.1
unnamed: R13.2, SJ7.3
unnamed: C37.1, U8.4
unnamed: C36.1, U8.1
unnamed: R16.2, SJ8.1
unnamed: R15.2, SJ8.3
unnamed: C42.1, U9.4
unnamed: C41.1, U9.1
unnamed: R18.2, SJ9.1
unnamed: R17.2, SJ9.3
unnamed: C47.1, U10.4
unnamed: C46.1, U10.1
unnamed: R20.2, SJ10.1
unnamed: R19.2, SJ10.3
unnamed: C52.1, U11.4
unnamed: C51.1, U11.1
unnamed: R22.2, SJ11.1
unnamed: R21.2, SJ11.3
unnamed: C57.1, U12.4
unnamed: C56.1, U12.1
unnamed: R24.2, SJ12.1
unnamed: R23.2, SJ12.3
unnamed: C62.1, U13.4
unnamed: C61.1, U13.1
unnamed: R26.2, SJ13.1
unnamed: R25.2, SJ13.3
unnamed: C67.1, U14.4
unnamed: C66.1, U14.1
unnamed: R28.2, SJ14.1
unnamed: R27.2, SJ14.3
unnamed: C72.1, U15.4
unnamed: C71.1, U15.1
unnamed: R30.2, SJ15.1
unnamed: R29.2, SJ15.3
unnamed: C77.1, U16.4
unnamed: C76.1, U16.1
unnamed: R32.2, SJ16.1
unnamed: R31.2, SJ16.3
unnamed: C82.1, U17.4
unnamed: C81.1, U17.1
unnamed: R34.2, SJ17.1
unnamed: R33.2, SJ17.3
unnamed: C87.1, U18.4
unnamed: C86.1, U18.1
unnamed: R36.2, SJ18.1
unnamed: R35.2, SJ18.3
unnamed: C92.1, U19.4
unnamed: C91.1, U19.1
unnamed: R38.2, SJ19.1
unnamed: R37.2, SJ19.3
unnamed: C97.1, U20.4
unnamed: C96.1, U20.1
unnamed: R40.2, SJ20.1
unnamed: R39.2, SJ20.3
unnamed: C102.1, U21.4
unnamed: C101.1, U21.1
unnamed: R42.2, SJ21.1
unnamed: R41.2, SJ21.3
unnamed: C107.1, U22.4
unnamed: C106.1, U22.1
unnamed: R44.2, SJ22.1
unnamed: R43.2, SJ22.3
unnamed: C112.1, U23.4
unnamed: C111.1, U23.1
unnamed: R46.2, SJ23.1
unnamed: R45.2, SJ23.3
unnamed: C117.1, U24.4
unnamed: C116.1, U24.1
unnamed: R48.2, SJ24.1
unnamed: R47.2, SJ24.3
unnamed: C122.1, U25.4
unnamed: C121.1, U25.1
unnamed: R50.2, SJ25.1
unnamed: R49.2, SJ25.3
unnamed: C127.1, U26.4
unnamed: C126.1, U26.1
unnamed: R52.2, SJ26.1
unnamed: R51.2, SJ26.3
unnamed: C132.1, U27.4
unnamed: C131.1, U27.1
unnamed: R54.2, SJ27.1
unnamed: R53.2, SJ27.3
unnamed: C137.1, U28.4
unnamed: C136.1, U28.1
unnamed: R56.2, SJ28.1
unnamed: R55.2, SJ28.3
unnamed: C142.1, U29.4
unnamed: C141.1, U29.1
unnamed: R58.2, SJ29.1
unnamed: R57.2, SJ29.3
unnamed: C147.1, U30.4
unnamed: C146.1, U30.1
unnamed: R60.2, SJ30.1
unnamed: R59.2, SJ30.3
unnamed: C152.1, U31.4
unnamed: C151.1, U31.1
unnamed: R62.2, SJ31.1
unnamed: R61.2, SJ31.3
unnamed: C157.1, U32.4
unnamed: C156.1, U32.1
unnamed: R64.2, SJ32.1
unnamed: R63.2, SJ32.3
unnamed: C162.1, U33.4
unnamed: C161.1, U33.1
unnamed: R66.2, SJ33.1
unnamed: R65.2, SJ33.3
unnamed: C167.1, U34.4
unnamed: C166.1, U34.1
unnamed: R68.2, SJ34.1
unnamed: R67.2, SJ34.3
unnamed: C172.1, U35.4
unnamed: C171.1, U35.1
unnamed: R70.2, SJ35.1
unnamed: R69.2, SJ35.3
unnamed: C177.1, U36.4
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

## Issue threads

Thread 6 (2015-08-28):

Incorrect Axis Markings

jrleeman, 2015-08-28:
The markings for the axes on the breakout are incorrect. The y-axis is fine, but the x is mirrored on the bottom and the z is marked "up" on both the top and bottom. From my reading of the data sheet, the z points down, so it should be marked with x in a circle on top, and the dot in a circle on bottom. The x direction marked on the top of the board is correct.

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

bboyho, 2020-06-02:
Hi,

Thanks for filing the issue. I confirmed the issue that you are seeing and you are correct. Unfortunately, the chip is EOL and was retired from the SparkFun catalog. Therefore, we are not able to revise the silkscreen. I'll be closing out this issue.

Closed 2020-06-02.

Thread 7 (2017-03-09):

Getting extreme readings

mikevanis, 2017-03-09:
Hi there,

I'm using this module with an ESP-12 module and I'm just running the Basic example. I'm getting very unusual readings. Here is a typical sample:

`X: 64895, Y: 425, Z: 64768`

What could this be? Have I got a damaged MAG3110? Is there a weird scale value register set somewhere? Any clues would be much appreciated.

mikevanis, 2017-03-15:
Hello lovely @sparkfun peeps? Any clues?

ejosh, 2017-03-15:
It looks like the code is set up to be pretty AVR specific, using the generic "int" data type. This works fine when used on various Uno/328 based boards, but may cause some issues with other core chips. The problem is that Arduino  uses a 16 bit int, while the ESP8266 uses a 32 bit int. I'd suggest changing the line right after "void loop()"
`  int x, y, z;`
to read
`  int16_t x, y, z;`

mikevanis, 2017-03-15:
Thanks for the suggestion @ejosh. I have edited parts of the library to use `int16_t` instead. I'm now getting these types of values:

`X: -1192, Y: 578, Z: -518`

Is that a "normal" output (putting aside hard/soft iron for a second)?

ejosh, 2017-03-15:
I haven't had a chance to get hands-on with this chip, but those values seem pretty reasonable compared to the tutorial. I'm going to go ahead and close this issue, feel free to reopen or start another issue if there are any other problems.

mikevanis, 2017-03-15:
Great, thanks @ejosh. I think you were right. I have corrected the library. Would it be useful to do a pull request for the data type changes I've made to [this repo](https://github.com/sparkfun/SparkFun_MAG3110_Breakout_Board_Arduino_Library)? Could be useful for people who are using non-AVR boards.

ejosh, 2017-03-20:
@mikevanis your updates would be greatly appreciated. If you wouldn't mind, could you submit the request to both this and the other repo you referenced? It may take a while to get processed (there's a pretty sizable backlog from how active the community is and only a few folks processing them), but at least if someone does a little digging the answer will be available.

Closed 2017-03-15.

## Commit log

2013-12-04 Initial commit - v12
    Initial commit of hardware version 12. Changes from v11:
    1.) 0402 to 0603 footprints
    2.) Jumper selects for I2C pullup/pulldown
    3.) Traces all routed directly away from IC
    4.) tRestrict under IC for even reflow
    5.) OSHW and Creative Commons info
    [MAG3110_Breakout.brd, MAG3110_Breakout.sch]
2013-12-10 Fixed pullup jumper and C3 position
    Removed both three pad jumpers. Replaced with one jumper to pullup I2C
    lines. Moved C3 closer to pin 8. Corrected 4 way VCC net in schematic.
    [MAG3110_Breakout.brd, MAG3110_Breakout.sch]
2013-12-11 Updated main IC to 1:1
    Updated footprint on main IC to 1:1 for better reflow and AOI.
    [MAG3110_Breakout.brd, MAG3110_Breakout.sch]
2014-01-13 Modified I2C pullup solder jumper
    Changed solder jumper for I2C pullup so that I2C lines will be
    completely floating if jumper is open. Moved capacitor bank to the left
    .005 grid spaces and moved resistors and cap on right side over .005 to
    the right, all for better trace routing. Changed int trace to be more
    direct to header.
    [MAG3110_Breakout.brd, MAG3110_Breakout.sch]
2014-02-24 Reordered Pinout
    1.) Reordered pinout to adhere to new I2C layout standard
    2.) Added "fake trace" to NC leg of IC for more uniform heat
    distribution.
    3.) Minor trace efficiency edits
    [MAG3110_Breakout.brd, MAG3110_Breakout.sch]
2014-04-21 Silk updates
    1.) Added axis silk to bottom.
    2.) Added SFE flame to top silk.
    3.) Moved existing silk to accommodate additions.
    [MAG3110_Breakout.brd, MAG3110_Breakout.sch]
2014-04-22 changed fiducials
    [MAG3110_Breakout.brd, MAG3110_Breakout.sch]
2014-04-22 created panel v12
    [MAG3110_Breakout-Panel-v12.brd]
2015-03-10 Adding demo sketch and updating directory names
    [MAG3110_Breakout-Panel-v12.brd]
2015-12-14 made larger panel
    [MAG3110_Breakout-Panel-v12.brd]
2016-10-25 Squashed 'Libraries/Arduino/' content from commit e798e5d
    git-subtree-dir: Libraries/Arduino
    git-subtree-split: e798e5d01f4523ffde3f9dc01292ebfc96ab786e

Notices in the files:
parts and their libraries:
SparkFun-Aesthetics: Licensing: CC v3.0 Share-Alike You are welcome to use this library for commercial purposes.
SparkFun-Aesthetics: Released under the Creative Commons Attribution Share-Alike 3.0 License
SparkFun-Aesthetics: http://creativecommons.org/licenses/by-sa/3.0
